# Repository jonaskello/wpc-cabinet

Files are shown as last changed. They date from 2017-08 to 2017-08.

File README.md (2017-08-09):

# WPC Pinball Standard Body Cabinet

This repo contains a sketchup model of a pinball cabinet in standard WPC body style and related information. I did this model to have a starting point for designing a virtual pinball cabinet.

To view the model download the [Sketchup Viewer](https://www.sketchup.com/products/sketchup-viewer). To edit the model download [Sketchup Make](https://www.sketchup.com/download?sketchup=make). Both these tools are free.

The sketchup file is [here](https://github.com/jonaskello/wpc-cabinet/archive/0.1.0.zip). You need to unzip it and find the file `wpc_cabinet.skp` and open it in Sketchup or the viewer.

If you find any mistakes in the model or the information below please open a [new issue](https://github.com/jonaskello/wpc-cabinet/issues/new) or make a post in this [thread](http://vpuniverse.com/forums/topic/3281-wpc-standard-body-sketchup/).

Here is a screenshot from the model:

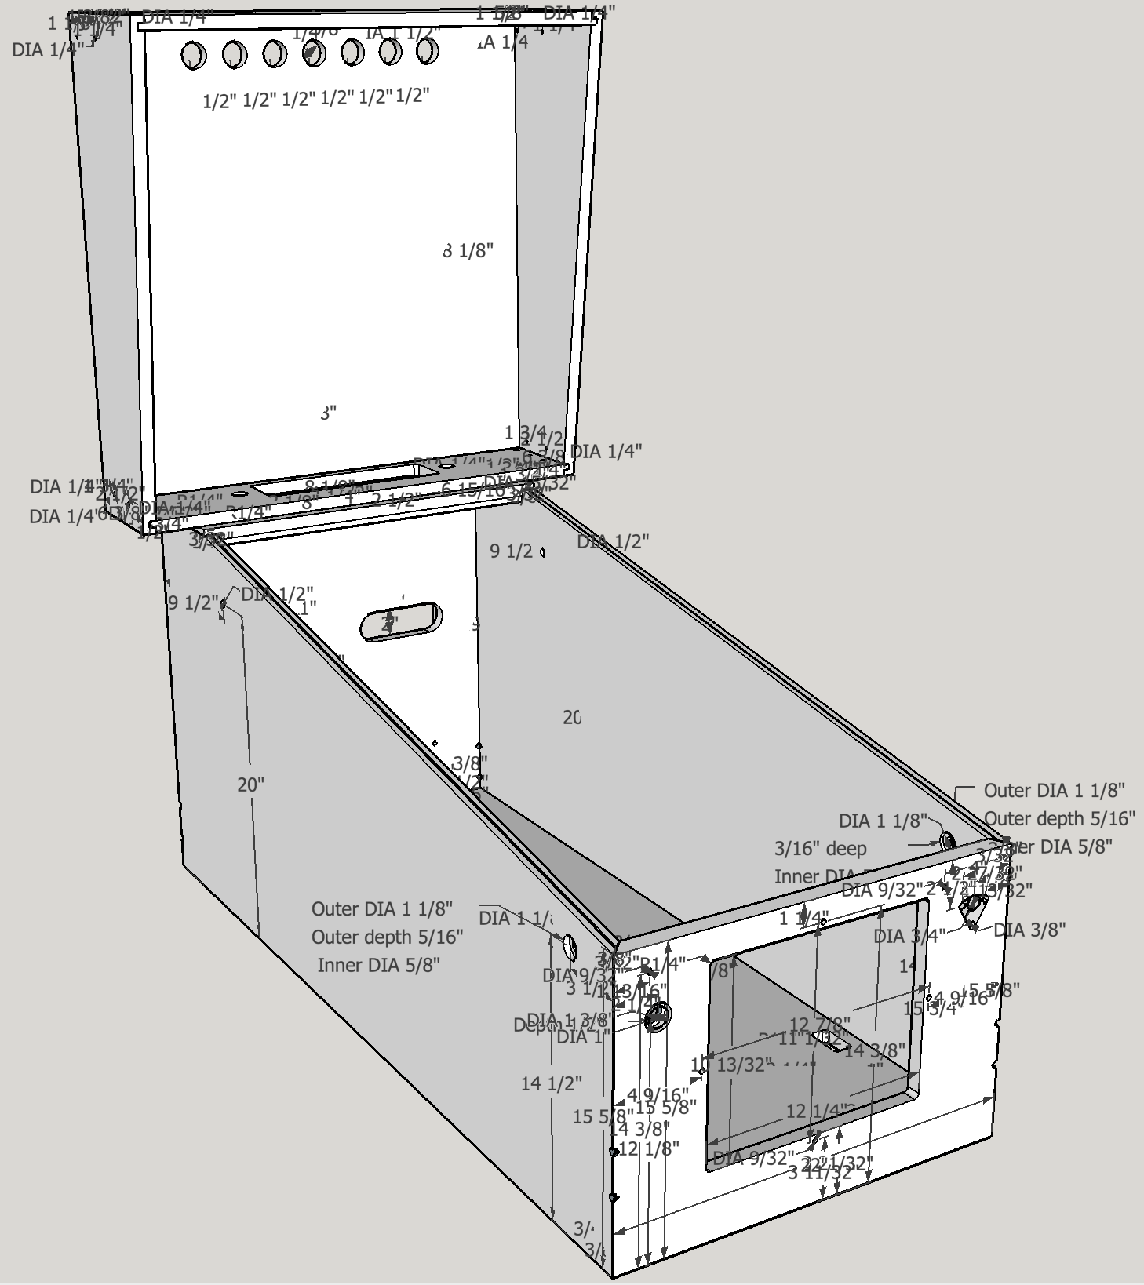
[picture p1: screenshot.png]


## Notes

* The model is made from measurements taken from my STTNG and IJ widebody games, but converted to standard body width. In addition to taking measurements from the physcial games I cross-checked with information found online which I have listed in [references](#references). Some measurements are only from online sources since they were hard to do without tearing down the games.

* I started out in millimeters but many measurements did not make sense so I switched to inch. To convert to millimeters multiply by 25.4. 

* The sides should have two holes for playfield support screws, but they are different for different playfields (at least my IJ and STTNG have their holes at different places). So those holes are omitted in the model.

* The joints are modelled as simple mitre joint. Both my IJ and STTNG uses "lock mitre joints". See below for more info on joints.

## Material

All components should be made of 3/4" thick birch playwood.

## Cabinet Joints

There are several ways to make the cabinet joints. The original way it was done in WPC cabinets is to use "lock mitre joints" but they require a special routing [bit](https://www.verktygsproffsen.se/produkt/Cobolt-Hornforbindningsfras-med-12-mm-skaft). Newer cabinets like my Stren LOTR uses a simpler joint. Another option is to just make butt joints without any angles, just make sure to adjust the measurements accordingly.

Below is a picuture of a lock mitre joint:

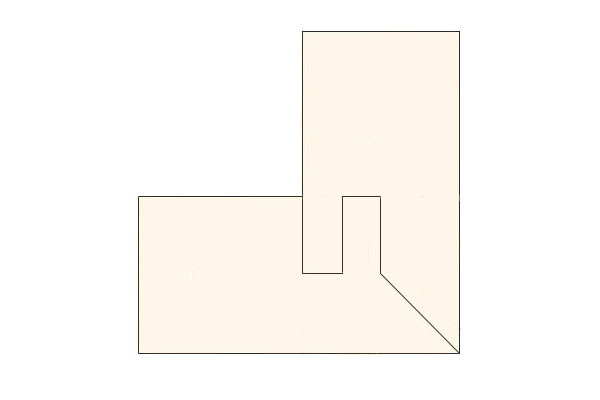
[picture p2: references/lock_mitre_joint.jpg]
Lock Mitre Joint


About lock mitre joints, see this [image](references/mitre-lock-joint.jpeg) from this [thread](https://pinside.com/pinball/forum/topic/peanuts-pinball). Also see [this image](http://pinballmakers.com/wiki/index.php/File:Mitre-bit.png) from this [page](http://pinballmakers.com/wiki/index.php/Construction). And [this page](https://howtobuildapinballmachine.wordpress.com/tag/miter-lock/) has some more information.

## Backbox Joints

The backbox joints should be according to the model.

# Components

## Cabinet Left/Right Side

| Cut | Tool | Description |
|:--- |:--- |:--- |
| Main Height | 23-1/2" | |
| Main Width | 51-1/2" | |
| Main Slope | Saw | Front height 15-5/8. Start 7-1/8" from back. |
| Flipper button | 1-1/8" Drill | 5/16" deep from outside. |
| Flipper button | 1-1/8" Drill | 3/16" deep from inside. |
| Flipper button | 5/8" Drill | |
| Backbox hinge  | 1/2" Drill | 20" from bottom, 1-1/2" from back. |
| Glass channel  | 3/32" slot cutter | 3/8" deep along the slope. |
| Leg Bolt From  | 3/8" drill | Two holes, 2 1/4 apart, in 45 degree angle. |
| Leg Bolt Back | 3/8" drill | Two holes, 2 1/4 apart, in 45 degree angle. |
| Bottom joint | 3/4" router | 1/4" deep. 3/8" from bottom.  |

## Cabinet Front

| Cut | Tool | Description |
|:--- |:--- |:--- |
| Main Height | 15-3/4" / 15-5/8" | Bevel cut 10 degrees. Outside height 15-5/8". |
| Main Width | 22" | |
| Bevel top | Saw | Cut to outside height 15-5/8". |
| Start button | 1-3/8" drill | 1/2" deep from outside. |
| Start button | 1" drill | |
| Coindoor | 1/4" router | Rectangular, 12-1/4" width, 10-13/32" height. |
| Coindoor | 9/32" drill | Two holes centered on left/right edge, width 12-7/8 between centers. |
| Coindoor | 9/32" drill | Two holes, centered on top/bottom edge, height 11-1/32" between centers. |
| Lockdown bar | 9/32" drill | Center 14-3/8" from bottom, 4" from right edge. |
| Lockdown bar | 9/32" drill | Center 14-3/8" from bottom, 1-13/16 from left edge. |
| Plunger | 3/4" drill | One hole. |
| Plunger | 3/8" drill | Three holes. |
| Plunger | 3/8" router | Cut between the holes. |
| Leg Bolt Left  | 3/8" drill | Two holes, 2 1/4 apart, in 45 degree angle. |
| Leg Bolt Right | 3/8" drill | Two holes, 2 1/4 apart, in 45 degree angle. |
| Bottom joint | 3/4" router | 1/4" deep. 3/8" from bottom.  |

## Cabinet Back

| Cut | Tool | Description |
|:--- |:--- |:--- |
| Main Height | 23-1/2" | |
| Main Width | 22" | |
| Vent #1 | 1" Drill | Two holes. |
| Vent #1 | Router | Rectangular width 6", height 2". |
| Vent #2 | 1" Drill | Two holes. |
| Vent #2 | Router | Rectangular width 6", height 2". |
| Power cord | 2-1/2 Drill | |
| Power cord | 5-1/16 Drill | Four holes. |
| Leg Bolt Left  | 3/8" drill | Two holes, 2 1/4 apart, in 45 degree angle. |
| Leg Bolt Right | 3/8" drill | Two holes, 2 1/4 apart, in 45 degree angle. |
| Bottom joint | 3/4" router | 1/4" deep. 3/8" from bottom.  |

## Cabinet Top

| Cut | Tool | Description |
|:--- |:--- |:--- |
| Main Height | 7-1/8" / 7" | Bevel cut 10 degrees. Inner height 7". |
| Main Width | 22" | |
| Backbox cables | 1/4" Router | Rectangular width 8-1/8", height 3-1/8". |
| Backbox nut #1 | 15/32" Drill | |
| Backbox nut #2 | 15/32" Drill | |
| Left joint | >=3/4" Router | 3/8 deep from bottom. |
| Right joint | >=3/4" Router | 3/8 deep from bottom. |

## Cabinet Bottom

| Cut | Tool | Description |
|:--- |:--- |:--- |
| Main Height | 50-1/2" | |
| Main Width | 21" | |
| Speaker | 5-1/2 hole saw | |
| Vent #1 | 1-1/2" drill | |
| Vent #2 | 1-1/2" drill | |
| On/Off switch  | 1/4" Router | Rectangular width 2-1/4", height 1-1/8". |

## Backbox Left/Right Side

| Cut | Tool | Description |
|:--- |:--- |:--- |
| Main Height | 28-1/2" | |
| Main Width | 9-7/8" | |
| Main Slope | Saw | Botttom width 6-3/8". |
| Bottom bracket | 1/4" Drill | Two holes, 2-1/2" apart. |
| Top bracket | 1/4" Drill | Two holes, 3" apart. |
| Top joint | 3/8" Router | 3/8" from top. 3/8" deep. |
| Bottom joint | 3/8" Router | 3/8" from bottom. 3/8" deep. |
| Back joint | >=3/4" Router | 3/8" from back. 3/8" deep. |

## Backbox Back

| Cut | Tool | Description |
|:--- |:--- |:--- |
| Main Height | 28-1/8" | |
| Main Width | 28" | |
| Vent | 1-1/2 Drill | Seven holes, 2-1/2 between centers.|

## Backbox Top

| Cut | Tool | Description |
|:--- |:--- |:--- |
| Main Height | 9-7/8" | |
| Main Width | 28" | Front bevel cut 7 degrees. |
| Left joint | >=3/4" Router | 3/8" from top. 3/8" deep. |
| Right joint | >=3/4" Router | 3/8" from top. 3/8" deep. |
| Back joint | >=3/4" Router | 3/8" from bottom. 3/8" deep. |
| Left bracket | 1/4" Drill | Two holes, 2" apart. 1-1/2" from back. |
| Right bracket  | 1/4" Drill | Two holes, 2" apart. 1-1/2" from back. |

## Backbox Bottom

| Cut | Tool | Description |
|:--- |:--- |:--- |
| Main Height | 5-23/32" | Front bevel cut 7 degrees. Bottom height 5-5/8". |
| Main Width | 28" | |
| Left joint | >=3/4" Router | 3/8" from bottom. 3/8" deep. |
| Right joint | >=3/4" Router | 3/8" from bottom. 3/8" deep. |
| Backbox nut #1 | 1" Drill | |
| Backbox nut #2 | 1" Drill | |
| Backbox cables | 1/4" Router | Rectangular width 11-1/2", height 3-1/4". |
| Left hinge bracket | 1/4" Drill | Three holes, 1-3/4" apart. 1/2" from back. |
| Right hinge bracket | 1/4" Drill | Three holes, 1-3/4" apart. 1/2" from back. |

# References

The files from these references are avaialble in the [references](references) folder.

Mameman pinball [plans](http://vpuniverse.com/forums/topic/171-plans-williams-widebody-cabinet-plans/).

Some nice CAD drawings in this [thread](https://pinside.com/pinball/forum/topic/bally-wms-cabinet-designs-help-needed).

Plunger drilling [template](http://mjrnet.org/pinscape/plunger-drilling.html).

Buttons hole [drilling](http://www.vpforums.org/index.php?showtopic=28014).

Playfield rear plastic [trim](http://www.marcospecialties.com/pinball-parts/03-8091).

Glass channel [tools](http://www.vpforums.org/index.php?showtopic=27208).

Coin door [measurements](http://www.actionpinball.com/pics/coindoor1_specs.gif).

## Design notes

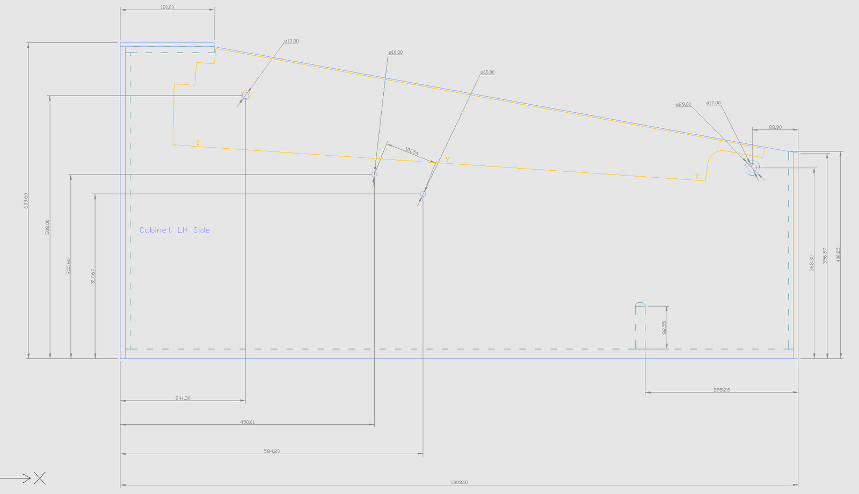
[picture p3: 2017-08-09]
references/cab_side_v2.png

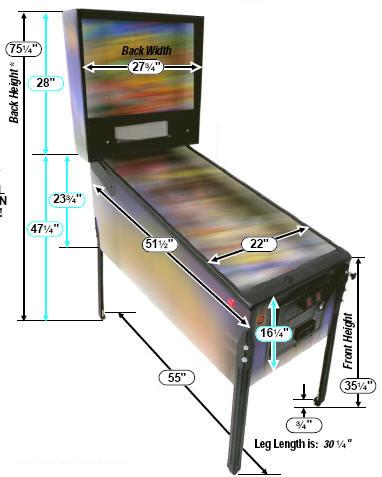
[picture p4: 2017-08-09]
references/dimensions_pinball.jpg

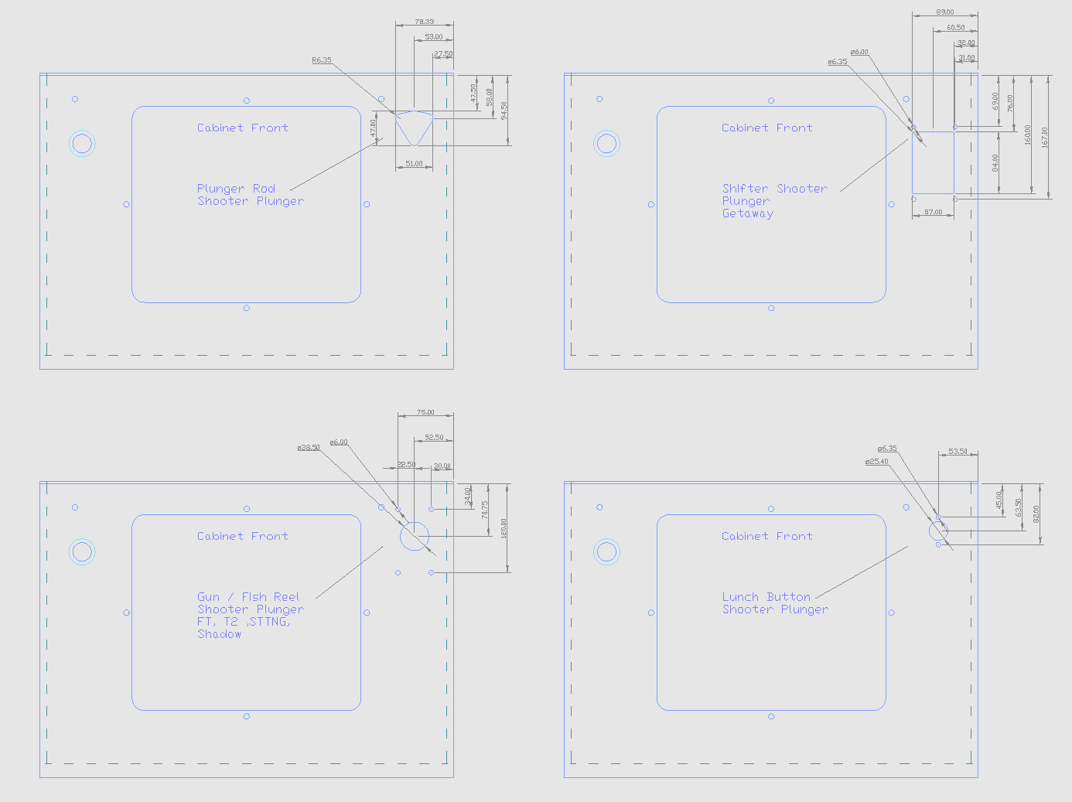
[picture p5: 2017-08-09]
references/front_shooters_v2.png

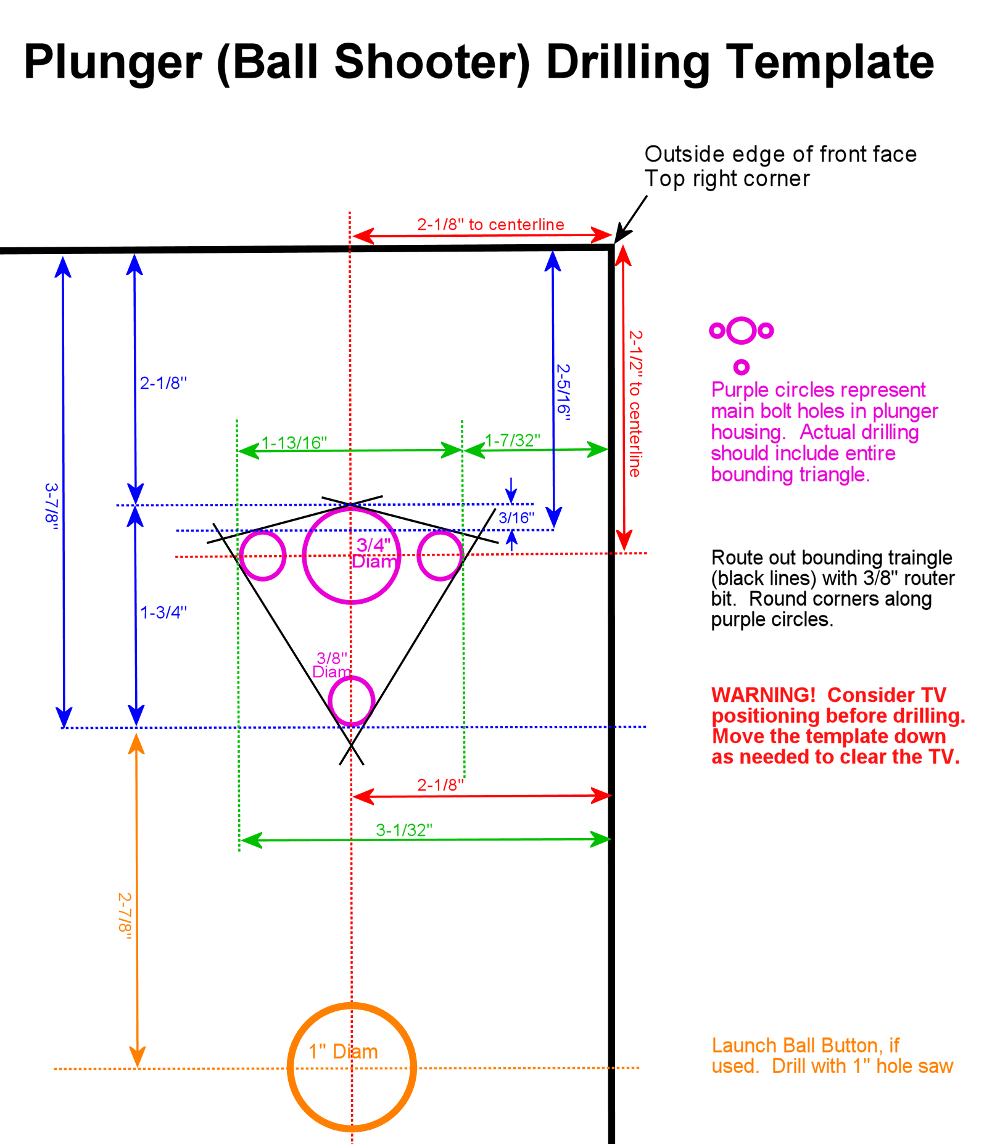
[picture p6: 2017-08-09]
references/plunger-drilling-template.png

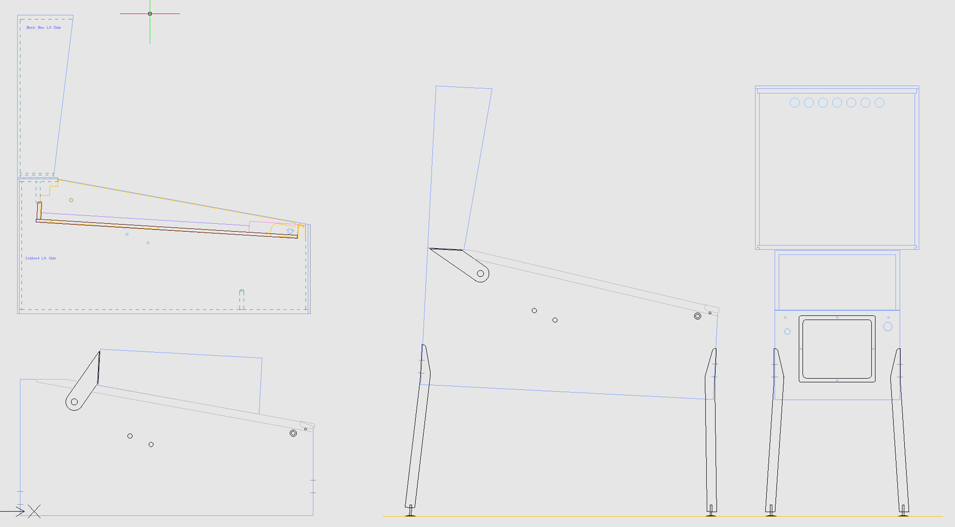
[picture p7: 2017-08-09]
references/complete_v1.png

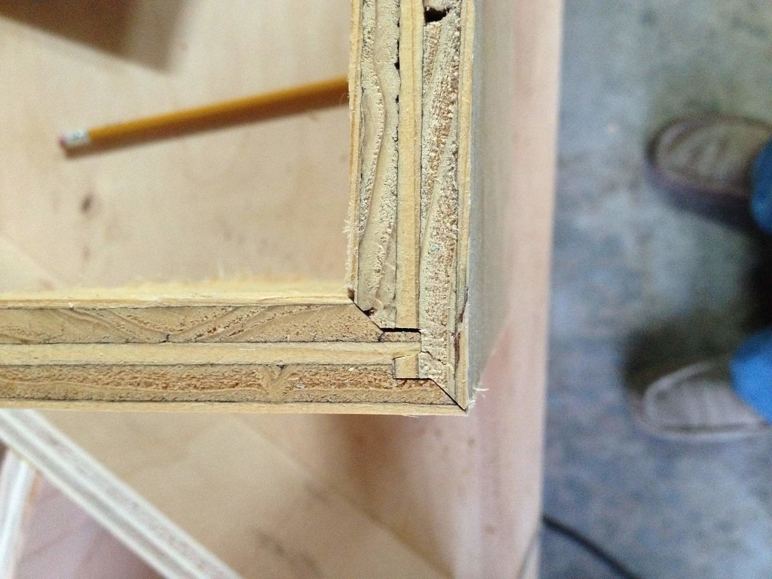
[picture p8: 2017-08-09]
references/mitre-lock-joint.jpeg

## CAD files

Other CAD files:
wpc_cabinet.f3d
wpc_cabinet.skp

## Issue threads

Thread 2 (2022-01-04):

Widebody version

Ashram56, 2022-01-04:
Good afternoon,

Would you have by chance a Widebody IJ model ? I'd like to renovate my IJ, and since I have access to a CNC router I'd very much like to build the cabinet from scratch if possible

Cheers

jonaskello, 2022-01-04:
Hi there!

Yes I actually have an IJ widebody, and also a STTNG widebody :-). The measurements in this plan comes from them but I've adjusted the width to standard body. I have not got around to building a cabinet from these plan yet so I cannot vouch for the accuracy though I did spend a lot of time trying to make them as accurate as possible.

Ashram56, 2022-02-01:
Thanks,

Did you create a model using the widebody measurements ? Since this model is standard size, I can't really use it for my Indy...

Also, do you have the mounting points locations for Indy and STTNG (for the playfield hinges) ?

Regards

Cheers

Ashram56, 2022-08-05:
Good morning, coming back on this topic, did you create a model using the original widebody measurements ? And any indication on the playfield hinges location ?

Cheers

jonaskello, 2022-08-05:
Yes, the measurements are from my original widebody games.

I'm not 100% certain but I think the playfield hinges can be at different locations for different games. I only have one widebody at home currently, the other one is at work so I cannot compare the hinges positions.

jonaskello, 2022-08-05:
Actually I saw now that I noted everything in the readme so you can just read this section :-)

https://github.com/jonaskello/wpc-cabinet#notes

jonaskello, 2022-08-05:
If you are looking for widebody measurements you can take the plans and just change the width back to widebody. Then you will have 100% original widebody measurements as all measurements are from widebody games and only the width was changed.

Ashram56, 2022-08-05:
With regards to the hinges, yes they are at different location.  That's the main problem, because it's rather hard to take a measurement of the hinge holes without disassembling first the original cabinet (specifically interested into Indy).

With regards to dimension, if only the width has been changed then indeed it's rather straightforward. I was thinking there might be other dimensions

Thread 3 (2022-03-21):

Locking miter join notes

mjrgh, 2022-03-21:
Your diagram of the locking miter join in the readme is true to the WPC originals, but the references you point to are a little misleading, since they're all about a different kind of locking miter, done with a special router bit.  The router-bit method is probably the most common way of making these joins these days, but it doesn't create quite the same kind of join, and not as good a join for plywood.  The problem with the router bits is that they're constrained by their one-bit-does-it-all design to cut a symmetrical, mirror-image pattern, so all of the features have to appear twice across the width of the join, which reduces their size.  That makes them fragile when rendered in plywood, which is why there's so much discussion in the references you point to about all of the downsides of this join and its questionable suitability for pin cabs.  The original WPC join, in contrast, isn't symmetrical, which allows its features to be coarse enough to work nicely with plywood.  And surprisingly, it's actually an easier and more reliable method - those special router bits are notoriously difficult to set up properly, and they require lots of special handling to get a halfway decent result with plywood.

Anyway, I thought I'd mention it in case you want to update your readme.  I got interested in this recently and learned how to execute the WPC joins, and I documented both methods in depth in my virtual pin cab build guide.  I can send you a link if you'd like to add that as a reference here.

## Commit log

2017-08-09 Backbox joints
2017-08-09 Rename in progress
    [WPC_Cabinet.skp]
2017-08-09 Add with new name
    [wpc_cabinet.skp]
2017-08-09 Add thread
2021-01-01 Conversion to Fusion360
    [wpc_cabinet.f3d]
